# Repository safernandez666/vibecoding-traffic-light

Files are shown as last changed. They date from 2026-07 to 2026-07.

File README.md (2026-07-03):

# Vibecoding Traffic Light 🚦

A physical traffic light hooked up to Claude Code.

- **Yellow blinking + beeps** → Claude needs your attention.
- **Red solid** → Claude is thinking.
- **Green solid** → Claude is done; keep coding.

<p align="center">
  Vibecoding Traffic Light in action
</p>

<p align="center">
  <a href="https://youtu.be/8MrP0tenx98">▶ Watch with audio</a>
</p>

---

## Hardware

- ESP32 DevKit
- Red LED → GPIO 25
- Yellow LED → GPIO 27
- Green LED → GPIO 26
- Passive buzzer → GPIO 33
- 220 Ω resistors for each LED

## Installation

1. Open `semaforo_server/semaforo_server.ino` in the Arduino IDE.
2. Set your WiFi credentials and a free static IP on your router:

```cpp
const char* SSID     = "YOUR_WIFI";   // change to your WiFi network
const char* PASSWORD = "YOUR_PASS";   // change to your WiFi password
IPAddress ip(192, 168, 1, 10);        // free static IP in your LAN range
```

3. Select the **ESP32 Dev Module** board and the correct serial port.
4. Upload the sketch (`Ctrl+U` / `Cmd+U`).
5. Open the Serial Monitor at 115200 baud and note the printed IP.

## Claude Configuration

The `claude-config.json` file contains the hooks so Claude can control the traffic light.

1. Copy its contents into your Claude Code configuration.
2. **Change the IP** (`192.168.1.10`) to the one your router assigned or the static one you configured.
3. Make sure your computer and the ESP32 are on the same network.

Web server endpoints:

| Endpoint | Method | Effect |
|---|---|---|
| `/alerta` | POST | 2 beep bursts + yellow blinking for 30 s |
| `/solo/amarillo`  | POST | Same as `/alerta` |
| `/solo/rojo` | POST | Red solid + short beep |
| `/solo/verde` | POST | Green solid + "done" chime |
| `/off` | POST | Turn everything off |

## Claude Code Integration

Claude uses `curl` to talk to the traffic light at these moments:

- `Notification` → `/alerta` (Claude needs you)
- `UserPromptSubmit` → `/solo/rojo` (Claude is thinking)
- `Stop` → `/solo/verde` (Claude is done)

## Important: use a free static IP

The code uses `192.168.1.10` by default. Before using it:

1. Log into your router.
2. Check that `192.168.1.10` is not assigned to another device, or change it to a free IP in your range.
3. (Optional but recommended) Reserve that IP for your ESP32's MAC address in the router's DHCP settings.

## 3D Print Models

All files are in [`/models`](models/):

- `caja_base.stl` — main body.
- `caja_tapa.stl` — back cover.
- `caja_completa.scad` — parametric source.

The case has three holes for the LED module, a buzzer grille on the front, a clip to hang on the monitor bezel, an ESP32 bay with a USB-C slot at the back, and an internal cavity for soldered wires.

### Renders

<p align="center">
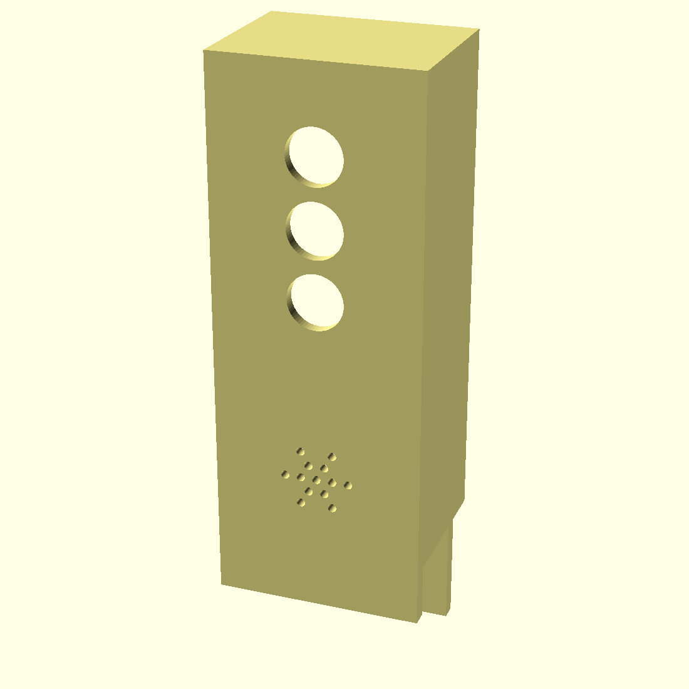
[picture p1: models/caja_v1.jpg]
Case render front
  
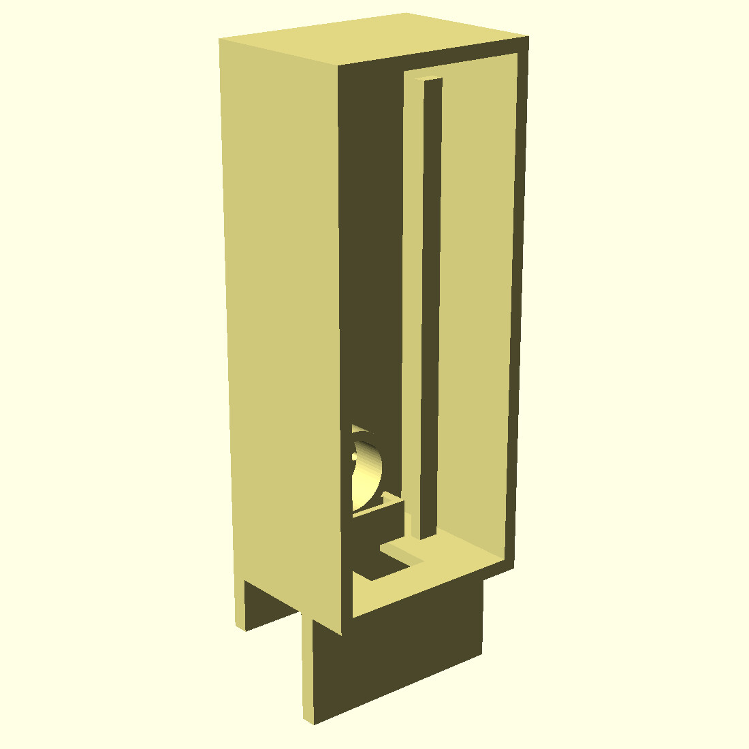
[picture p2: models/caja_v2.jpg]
Case render angled
  
</p>

<p align="center">
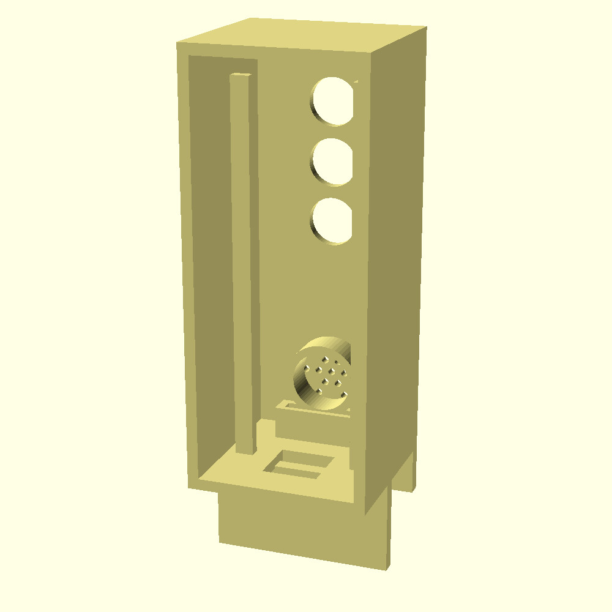
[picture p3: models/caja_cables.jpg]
Case internal wiring cavity
  
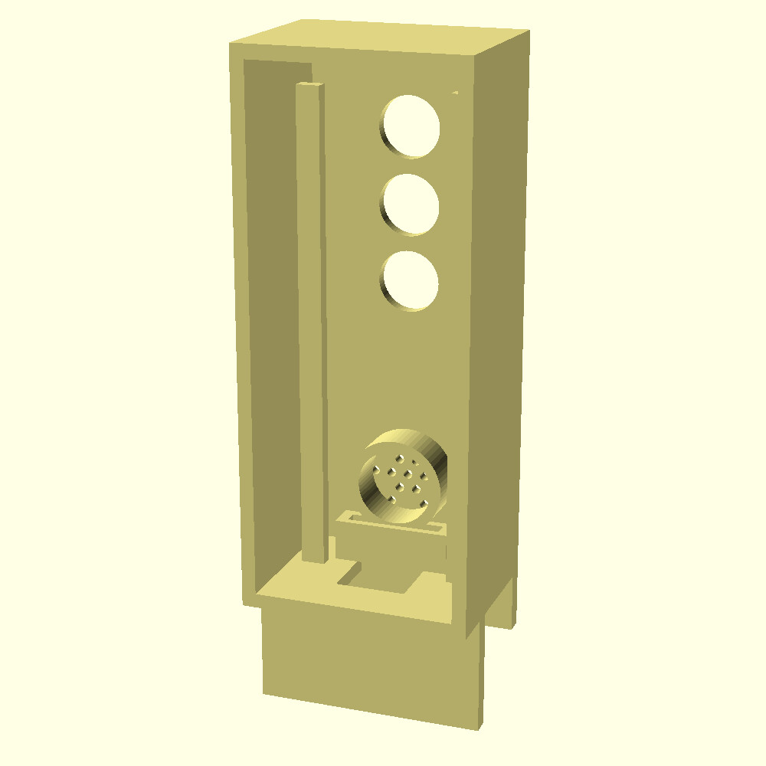
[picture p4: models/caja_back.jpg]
Case back ESP bay
  
</p>

### Things to check before printing

Open `caja_completa.scad` and adjust:

- `led_pitch` / `led_d` — spacing and diameter of your LED module.
- `mon_thick` — thickness of your monitor bezel (for the clip).
- `usb_y` / `usb_w` — position/width of the USB-C slot depending on how you mount the ESP32.

Export STLs:

```bash
openscad -D 'part="base"' -o caja_base.stl caja_completa.scad
openscad -D 'part="tapa"' -o caja_tapa.stl caja_completa.scad
```

## License

MIT

---

¿Hablas español? Encontrá la versión en castellano en [`README.es.md`](README.es.md).

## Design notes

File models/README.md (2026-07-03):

# Semáforo de estado para Claude Code (ESP32)

Semáforo físico (3 LEDs + buzzer) que reacciona a la terminal de Claude Code:
se controla por HTTP y los hooks de Claude le disparan los cambios.

- **Rojo** = Claude está trabajando
- **Amarillo** = Claude pide tu atención (permiso / idle) → titila + 2 tandas de buzz, 30 s
- **Verde** = Claude terminó → sonido largo

---

## Hardware

- Placa: **NodeMCU ESP32 (ESP-32S / WROOM-32)**, USB-C, chip USB-serie Silicon Labs CP2102.
- Puerto serie en la Mac: `/dev/cu.usbserial-0001` · 115200 baud.
- En Arduino IDE: placa **"ESP32 Dev Module"**.

### Pines

| Componente | GPIO |
|---|---|
| LED rojo | 25 |
| LED amarillo | 27 |
| LED verde | 26 |
| Buzzer (pasivo) | 33 |

Evitar como salida: 34/35/36/39 (solo entrada), 6–11 (flash), 0/2/5/12/15 (strapping).

### Cableado

- Cada LED: pata larga (+) → resistencia 220 Ω → su GPIO · pata corta (–) → GND.
- Buzzer: pata larga (+) → GPIO33 · pata corta (–) → GND. (Pasivo, se maneja con `tone()`.)
- Alimentación: USB-C 5V.

---

## Software (firmware)

Archivo: `semaforo_server.ino` (Arduino / ESP32). IP fija **192.168.1.10**.

### Endpoints (POST)

| Endpoint | Efecto |
|---|---|
| `/solo/rojo` | rojo (apaga el resto) + beep |
| `/solo/amarillo` o `/alerta` | ALERTA: amarillo titila + 2 tandas de buzz, 30 s |
| `/solo/verde` | verde + sonido largo (Claude terminó) |
| `/off` | apaga todo y corta la alerta |

Prueba rápida (Python):

```python
import requests
requests.post("http://192.168.1.10/alerta")
requests.post("http://192.168.1.10/solo/verde")
requests.post("http://192.168.1.10/off")
```

### Parámetros ajustables (arriba del .ino)

`ALERTA_MS` (30 s) · `BLINK_MS` (velocidad titileo) · `TANDAS` / `PITIDOS` (buzz inicial).

---

## Hooks de Claude Code

Archivo: `claude_hooks.json`. Va dentro de `~/.claude/settings.json`
(clave `hooks` de nivel superior; si ya hay `permissions`, agregar al lado, no pisar).

```json
{
  "hooks": {
    "Notification":     [ { "hooks": [ { "type": "command", "command": "curl -s --max-time 2 -X POST http://192.168.1.10/alerta" } ] } ],
    "Stop":             [ { "hooks": [ { "type": "command", "command": "curl -s --max-time 2 -X POST http://192.168.1.10/solo/verde" } ] } ],
    "UserPromptSubmit": [ { "hooks": [ { "type": "command", "command": "curl -s --max-time 2 -X POST http://192.168.1.10/solo/rojo" } ] } ]
  }
}
```

Después: reiniciar Claude Code · verificar con `/hooks` · validar JSON con
`python3 -m json.tool ~/.claude/settings.json`.

**Seguridad (pendiente opcional):** el endpoint hoy es abierto en la LAN.
Se puede pasar a hook tipo `http` con header `X-Token` y validar el token en el firmware.

---

## Caja 3D

- `caja_base.stl` — cuerpo (imprimir).
- `caja_tapa.stl` — tapa trasera.
- `caja_completa.scad` — fuente paramétrico.

Contiene: 3 agujeros para los LEDs del módulo + rejilla del buzzer al frente,
clip para el borde del monitor arriba, bahía para la ESP con ranura USB-C atrás,
y cámara interna para los cables soldados.

### Medidas a verificar antes de imprimir (en el .scad)

- `led_pitch` / `led_d` — separación y diámetro de los LEDs del módulo.
- `mon_thick` — espesor del borde del monitor (para el clip).
- `usb_y` / `usb_w` — posición/ancho de la ranura USB-C según cómo apoyes la ESP.

Reexportar: `openscad -D 'part="base"' -o caja_base.stl caja_completa.scad`
(y `part="tapa"` para la tapa).

### Renders (JPG)

`caja_v1.jpg`, `caja_v2.jpg` (vistas), `caja_cables.jpg`, `caja_back.jpg` (interior / bahía ESP).

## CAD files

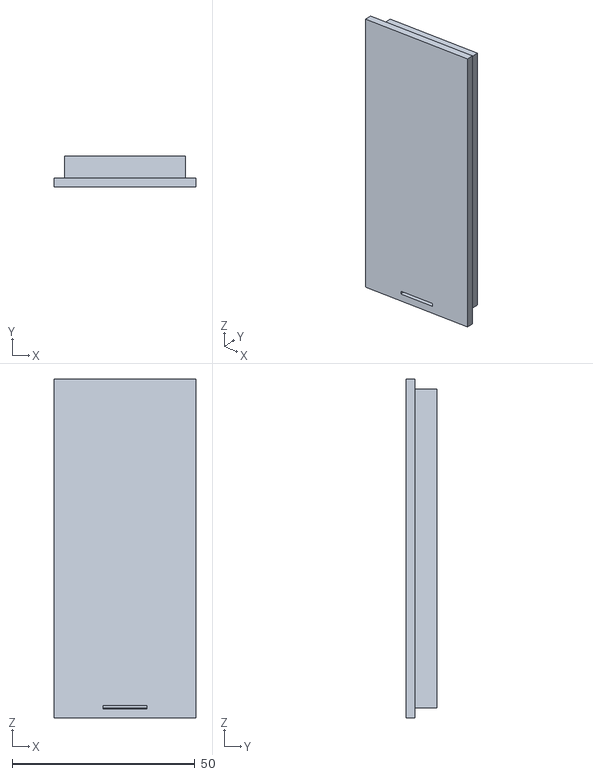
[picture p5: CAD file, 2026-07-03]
models/caja_tapa.stl
38.8 x 8.40 x 92.8

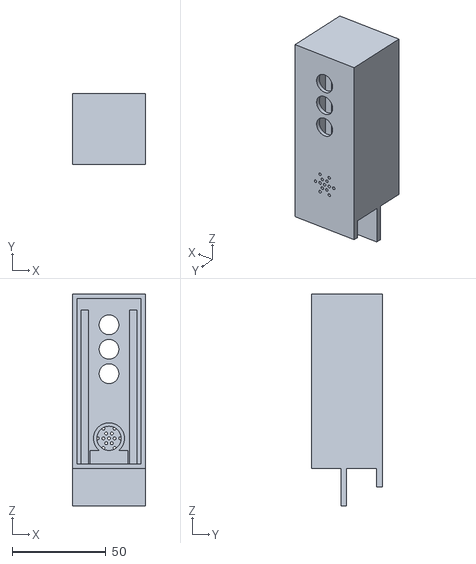
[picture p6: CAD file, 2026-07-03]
models/caja_base.stl
38.8 x 37.6 x 112.8

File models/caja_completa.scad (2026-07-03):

// Caja completa: modulo semaforo (3 LEDs) + buzzer + ESP32 adentro
// con orificio USB-C, clip al monitor, y tapa trasera.
// >>> AJUSTAR: led_pitch, led_d, mon_thick, usb_w/usb_y <<<
$fn=64;
part = "base";  // "base" o "tapa"

// modulo (3 LEDs)
led_d=10.5; led_pitch=13; led_top=14; module_w=16;
// buzzer
buzz_d=12.5; spk_hole_d=1.6; spk_from_bot=16;
// ESP32 (plana contra la pared trasera)
esp_thk=13;          // alto de la ESP con componentes
// caja
inner_w=34; inner_h=88; inner_d=33;   // +8mm de camara para cables soldados
wall=2.4; front_wall=2.2;
// USB-C (ranura en la base)
usb_w=12; usb_len=12; usb_y=6;   // usb_y = distancia desde la pared trasera
// clip monitor
mon_thick=16; tab_thk=3; front_drop=10; back_drop=20;

out_w=inner_w+2*wall; out_d=wall+inner_d+front_wall; out_h=inner_h+2*wall;
fy=out_d-front_wall; cx=out_w/2; bx0=cx-module_w/2;

module led_holes(){ for(i=[0:2]){ z=wall+inner_h-led_top-i*led_pitch;
  translate([cx,fy-1,z]) rotate([-90,0,0]) cylinder(h=front_wall+2,d=led_d);} }
module grille(){ cz=spk_from_bot;
  translate([cx,fy-1,cz]) rotate([-90,0,0]) cylinder(h=front_wall+2,d=spk_hole_d);
  for(a=[0:60:300]) for(r=[3,6])
    translate([cx+r*cos(a),fy-1,cz+r*sin(a)]) rotate([-90,0,0]) cylinder(h=front_wall+2,d=spk_hole_d); }
module body(){ difference(){
  cube([out_w,out_d,out_h]);
  translate([wall,-1,wall]) cube([inner_w,wall+inner_d+1,inner_h]);   // cavidad, abierta atras
  led_holes(); grille();
  // ranura USB-C en la base (pared inferior z=0..wall)
  translate([cx-usb_w/2, wall+usb_y, -1]) cube([usb_w, usb_len, wall+2]);
} }
module clip(){ front_y=out_d-tab_thk; back_y=front_y-mon_thick-tab_thk;
  translate([0,front_y,-front_drop]) cube([out_w,tab_thk,front_drop+0.5]);
  translate([0,back_y,-back_drop]) cube([out_w,tab_thk,back_drop+0.5]); }
// encastre modulo (canal frontal-inferior)
module module_channel(){ ch_h=7; th=2.4; my=fy-9;
  difference(){
    translate([bx0-2,my,wall]) cube([module_w+4,th+2.8,ch_h]);
    translate([bx0-0.2,my+1.4-0.1,wall+1.6]) cube([module_w+0.4,th,ch_h]); } }
// copa buzzer
module buzzer_cup(){ cl=7;
  difference(){
    translate([cx,fy-cl,spk_from_bot]) rotate([-90,0,0]) cylinder(h=cl,d=buzz_d+4);
    translate([cx,fy-cl-1,spk_from_bot]) rotate([-90,0,0]) cylinder(h=cl+2,d=buzz_d+0.4); } }
// tope de la ESP: repisas que la empujan al fondo (queda plana contra la pared trasera)
module esp_stops(){ for(x=[wall+2, out_w-wall-6])
  translate([x,wall+esp_thk,wall]) cube([4,2.4,inner_h-6]); }

module base(){ color("Khaki"){ body(); clip(); module_channel(); buzzer_cup(); esp_stops(); } }

// tapa trasera (cierra la parte de atras despues de soldar y meter la ESP)
module tapa(){ clr=0.4; lip=6; bt=2.4;
  color("Salmon"){
  difference(){
    union(){
      cube([out_w, bt, out_h]);   // placa trasera (en el plano y=0)
      translate([wall+clr, bt, wall+clr])
        difference(){
          cube([inner_w-2*clr, lip, inner_h-2*clr]);
          translate([2.4,-1,2.4]) cube([inner_w-2*clr-4.8, lip+2, inner_h-2*clr-4.8]);
        }
    }
    // ranura USB-C tambien en el borde de la tapa
    translate([cx-usb_w/2, -1, wall]) cube([usb_w, bt+2, 1]);
  } }
}

if(part=="base") base(); else tapa();

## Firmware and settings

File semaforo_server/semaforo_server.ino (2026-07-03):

// semaforo_server.ino  -  Semaforo + buzzer (ESP32 / Arduino)
// Red: Tamborini1D  |  IP fija: 192.168.1.10
// LEDs: rojo=25  amarillo=27  verde=26   Buzzer: 33
//
// /alerta -> Claude pide atencion:
//    * 2 tandas de pitidos al principio (para llamarte)
//    * luego el amarillo sigue titilando EN SILENCIO hasta los 30s
// Todo NO BLOQUEANTE: el server sigue respondiendo mientras corre.

#include <WiFi.h>
#include <WebServer.h>

const char* SSID = "RED";
const char* PASSWORD = "PASS";
IPAddress ip(192,168,1,10), gateway(192,168,1,1), subnet(255,255,255,0), dns(192,168,1,1);

const int ROJO=25, AMARILLO=27, VERDE=26, BUZZER=33;
const int T_ROJO=1500, T_AMARILLO=2000, T_VERDE=2600;

// ---- parametros de la alerta ----
const unsigned long ALERTA_MS = 30000;  // duracion total (titileo del LED)
const unsigned long BLINK_MS  = 350;    // velocidad del titileo
const int           TANDAS    = 2;      // cuantas tandas de buzz al principio
const int           PITIDOS   = 3;      // pitidos por tanda
const int           PITIDO_MS = 120;    // duracion de cada pitido
const int           GAP_MS    = 90;     // silencio entre pitidos
const int           TANDA_GAP = 500;    // silencio entre tandas

// ---- estado (no bloqueante) ----
bool          alerta_on   = false;
unsigned long alerta_fin  = 0;
unsigned long blink_next  = 0;
bool          blink_fase  = false;

WebServer server(80);

void escribir(bool r,bool a,bool v){ digitalWrite(ROJO,r); digitalWrite(AMARILLO,a); digitalWrite(VERDE,v); }
void beep(int f,int ms){ tone(BUZZER,f); delay(ms); noTone(BUZZER); }
void done_chime(){ beep(1600,150); beep(2000,150); beep(2500,500); }

// Las 2 tandas de pitidos suenan una sola vez al iniciar la alerta.
// Son cortas (~2s en total) asi que las hago aca directo; el resto del
// tiempo (titileo silencioso) es lo que corre no bloqueante en loop().
void tandas_iniciales(){
  for (int t=0; t<TANDAS; t++){
    for (int p=0; p<PITIDOS; p++){
      digitalWrite(AMARILLO, HIGH); tone(BUZZER, T_AMARILLO);
      delay(PITIDO_MS);
      digitalWrite(AMARILLO, LOW);  noTone(BUZZER);
      delay(GAP_MS);
    }
    delay(TANDA_GAP);
  }
}

void iniciar_alerta(){
  escribir(0,0,0);
  tandas_iniciales();          // 2 tandas de sonido para llamarte
  alerta_on  = true;
  alerta_fin = millis() + ALERTA_MS;
  blink_next = 0;
  blink_fase = false;
}
void cortar_alerta(){
  alerta_on = false;
  digitalWrite(AMARILLO, LOW);
  noTone(BUZZER);
}

void setup(){
  Serial.begin(115200);
  pinMode(ROJO,OUTPUT); pinMode(AMARILLO,OUTPUT); pinMode(VERDE,OUTPUT);
  escribir(0,0,0); noTone(BUZZER);

  WiFi.mode(WIFI_STA);
  WiFi.config(ip,gateway,subnet,dns);
  WiFi.begin(SSID,PASSWORD);
  while(WiFi.status()!=WL_CONNECTED){ delay(300); Serial.print("."); }
  Serial.print("\nIP del modulo: "); Serial.println(WiFi.localIP());

  server.on("/alerta",        HTTP_POST, [](){ iniciar_alerta(); server.send(200,"text/plain","ok alerta\n"); });
  server.on("/solo/amarillo", HTTP_POST, [](){ iniciar_alerta(); server.send(200,"text/plain","ok alerta\n"); });
  server.on("/solo/rojo",  HTTP_POST, [](){ cortar_alerta(); escribir(1,0,0); beep(T_ROJO,120); server.send(200,"text/plain","ok solo rojo\n"); });
  server.on("/solo/verde", HTTP_POST, [](){ cortar_alerta(); escribir(0,0,1); done_chime();      server.send(200,"text/plain","ok solo verde\n"); });
  server.on("/off",        HTTP_POST, [](){ cortar_alerta(); escribir(0,0,0); server.send(200,"text/plain","ok off\n"); });

  server.begin();
  Serial.println("Servidor listo en http://192.168.1.10");
}

void loop(){
  server.handleClient();

  // titileo SILENCIOSO del amarillo hasta cumplir los 30s
  if (alerta_on){
    if (millis() >= alerta_fin){
      cortar_alerta();
    } else if (millis() >= blink_next){
      blink_fase = !blink_fase;
      blink_next = millis() + BLINK_MS;
      digitalWrite(AMARILLO, blink_fase ? HIGH : LOW);   // sin tone(): mudo
    }
  }
}

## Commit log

2026-07-03 Initial commit: ESP32 traffic light for Claude vibecoding
2026-07-03 Add 3D print models, renders and multi-language docs
    [caja_base.stl, caja_completa.scad, caja_tapa.stl]
